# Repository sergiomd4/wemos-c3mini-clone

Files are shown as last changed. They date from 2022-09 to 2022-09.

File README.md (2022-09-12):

C3 Mini Clone
========================================

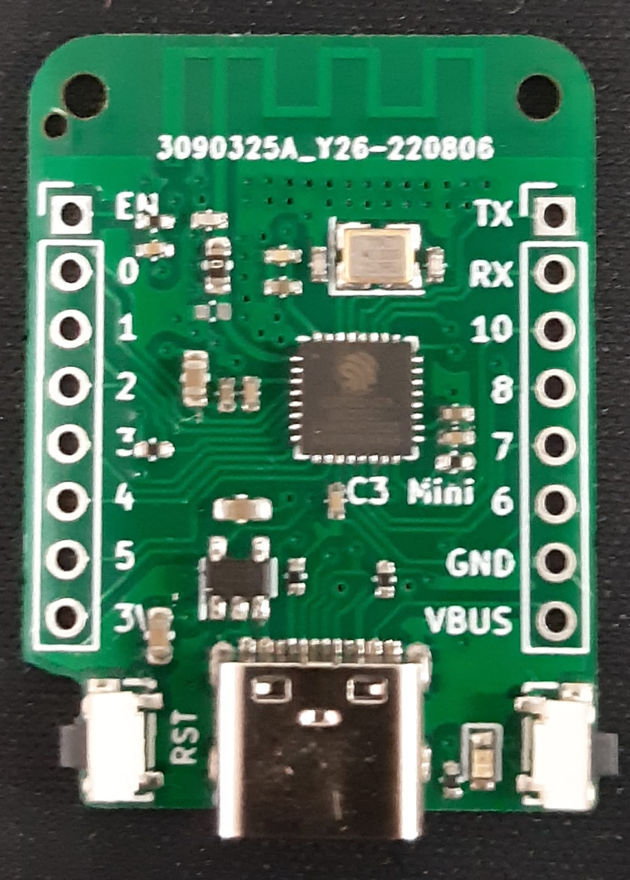
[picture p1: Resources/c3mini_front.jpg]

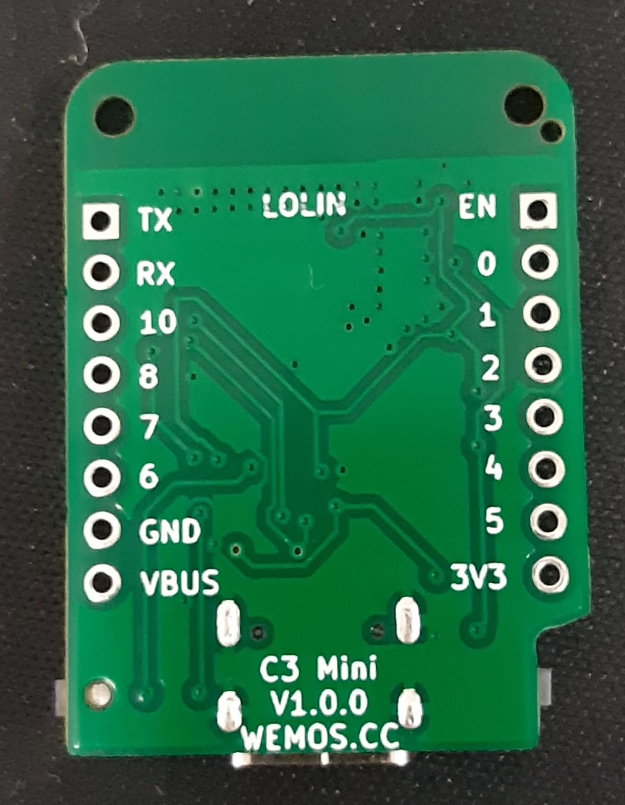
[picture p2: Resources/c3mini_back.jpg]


C3 Mini Clone is a mini WiFi and Bluetooth5 (LE) board based on ESP32-C3FH4

Features
-------------------

* Based on ESP32-C3 WiFi & Bluetooth LE RISC-V Single-Core CPU
* Type-C USB
* 4MB Flash
* 12x IO
* ADC, I2C, SPI, UART
* Compatible with LOLIN D1 mini shields
* Compatible with MicroPython, Arduino, CircuitPython and ESP-IDF
* Default firmware: MicroPython

Technical specifications
-------------------

* Operating Voltage           3.3 V
* Digital I/O Pins            12
* Clock Speed                 160 MHz
* Flash                       4MB
* Size                        34.3*25.4 mm
* Weight                      2.4 g

Repository Contents
-------------------

* **/Production** - Gerber files, drill files, BOM, CPL file
* **/Hardware** - KiCad PCB files
* **/Documents** - Schematics pdf, datasheet

The switch footprint is in the library inside the Hardware folder.

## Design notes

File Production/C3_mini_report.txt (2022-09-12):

Informe de estadísticas de la placa
=============================
- Fecha: 12/09/2022 17:24:44
- Proyecto: C3_mini
- Nombre de placa: C3_mini

Placa
-----
- Ancho: 25,4092 mm
- Alto: 34,1771 mm
- Área: 848,2955 mm cuadrados

Pads
----
- Agujero pasante: 21
- SMD: 125
- Conector: 1
- NPTH: 2

Vías
----
- Vías pasantes: 74
- Ciega/Enterrada: 0
- Microvías: 0

Componentes
----------

| | Lado frontal | Lado trasero | Total |
|---|---|---|---|
|THT: | 2  | 0  | 2  |
|SMD: | 29  | 0  | 29  |
|Total:  | 31  | 0  | 31  |
| | | | |

Agujeros de taladros
-----------

| Cantidad | Forma |  Tamaño X |  Tamaño Y | Revestido | Vía/Pad | Capa inicial | Capa final |
|---|---|---|---|---|---|---|---|
| 74 | Redondo | 0,4000 mm | 0,4000 mm | PTH | Vía | F.Cu | B.Cu |
| 16 | Redondo | 1,0000 mm | 1,0000 mm | PTH | Pad | F.Cu | B.Cu |
| 2 | Redondo | 0,6000 mm | 0,6000 mm | NPTH | Pad | F.Cu | B.Cu |
| 2 |  Ranura | 1,7000 mm | 0,6000 mm | PTH | Pad | F.Cu | B.Cu |
| 2 |  Ranura | 1,4000 mm | 0,6000 mm | PTH | Pad | F.Cu | B.Cu |
| 1 | Redondo | 0,3000 mm | 0,3000 mm | PTH | Pad | F.Cu | B.Cu |

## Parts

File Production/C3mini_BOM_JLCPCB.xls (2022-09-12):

Comment | Designator | Footprint | JLCPCB Part #
SW_2x4x3.5 | SW2,SW1,SW2 | EOS:ST-1114A | C585239
IA0503S | PS1 | Package_TO_SOT_SMD:SOT-23-5 | C82942
1uF | C11,C4,C5,C4,C11 | Capacitor_SMD:C_0402_1005Metric | C52923
15pF | C12,C13,C12 | Capacitor_SMD:C_0402_1005Metric | C1548
100nF | C8,C14,C7,C6,C7,C14,C8 | Capacitor_SMD:C_0402_1005Metric | C1525
5.1k | R2,R1,R2 | Resistor_SMD:R_0402_1005Metric | C25905
10k | R6,R3,R4,R3,R6 | Resistor_SMD:R_0402_1005Metric | C25744
2k | R5 | Resistor_SMD:R_0402_1005Metric | C4109
USB_C_16P | J1 | Connector_USB:USB_C_Receptacle_Palconn_UTC16-G | C2760486
40MHz | Y1 | Crystal:Crystal_SMD_TXC_7M-4Pin_3.2x2.5mm | C9010
10nF | C1 | Capacitor_SMD:C_0402_1005Metric | C15195
ESP32-C3 | U1 | Package_DFN_QFN:QFN-32-1EP_5x5mm_P0.5mm_EP3.45x3.45mm | C2858491
1pF | C15 | Capacitor_SMD:C_0402_1005Metric | C1550
0R | L1 | Inductor_SMD:L_0603_1608Metric | C21189
LED_0603_B | LED1 | LED_SMD:LED_0603_1608Metric | C74343
10uF | C3,C17,C18,C17,C3 | Capacitor_SMD:C_0603_1608Metric | C19702

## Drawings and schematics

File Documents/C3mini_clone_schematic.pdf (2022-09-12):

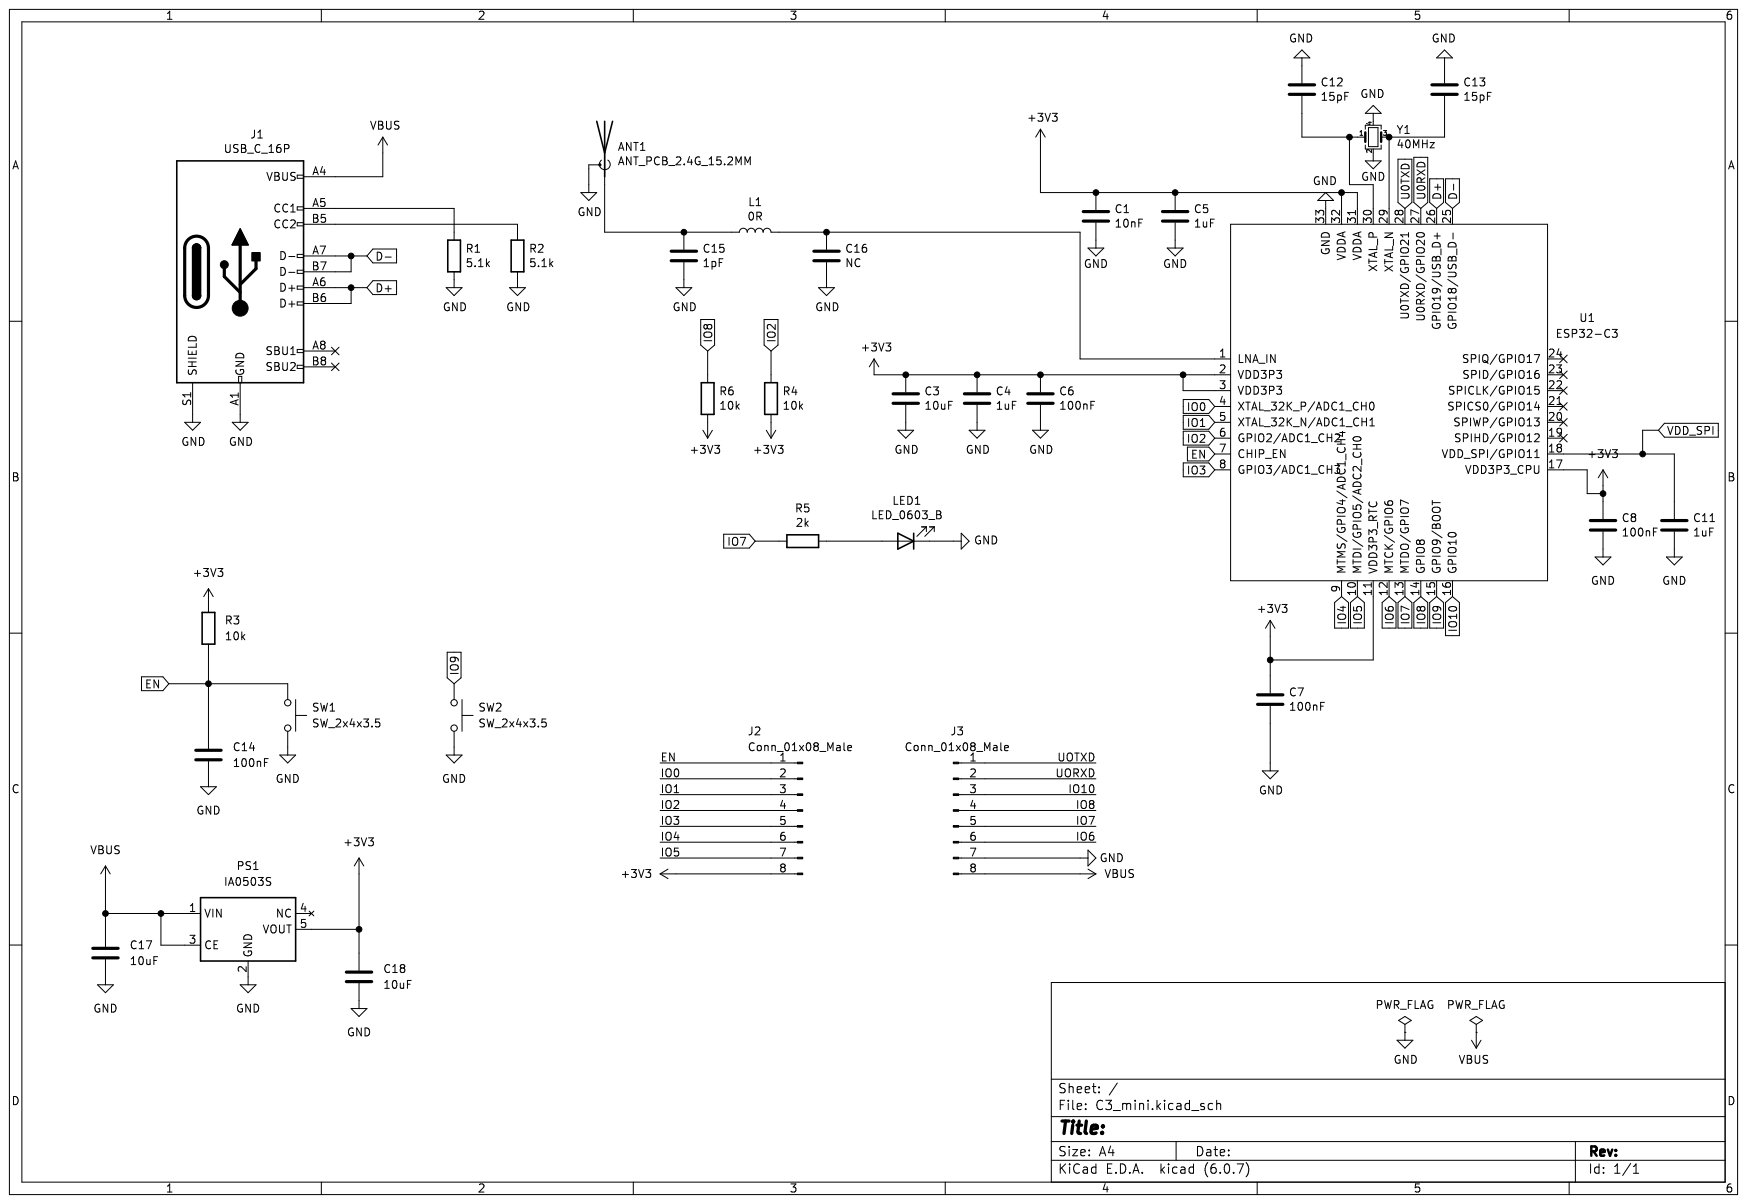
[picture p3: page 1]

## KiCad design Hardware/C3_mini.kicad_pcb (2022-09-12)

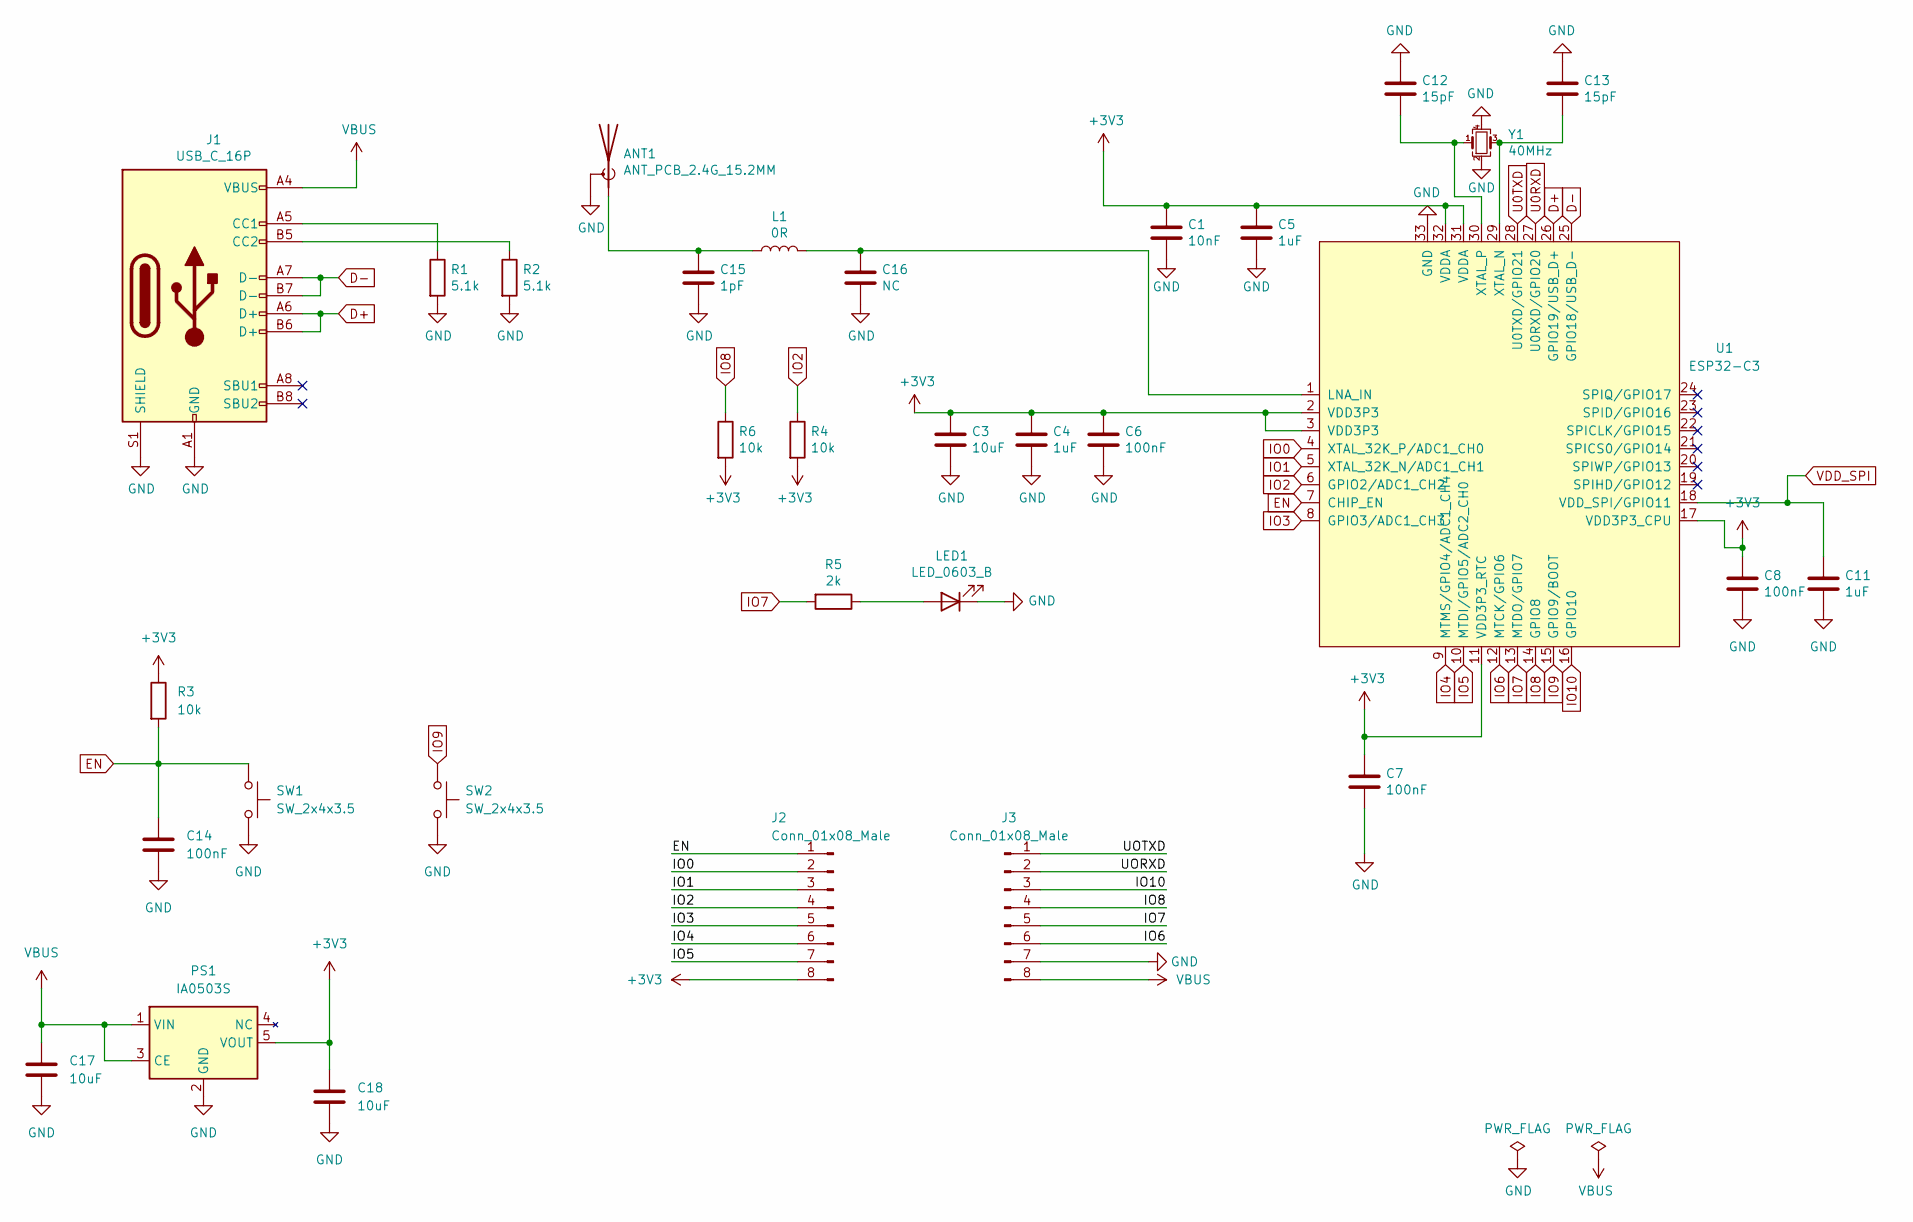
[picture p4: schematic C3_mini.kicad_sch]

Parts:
ANT1: ANT_PCB_2.4G_15.2MM; Texas_SWRA117D_2.4GHz_Right
C1: 10nF; C_0402_1005Metric
C3, C17, C18: 10uF; C_0603_1608Metric
C4, C5, C11: 1uF; C_0402_1005Metric
C6, C7, C8, C14: 100nF; C_0402_1005Metric
C12, C13: 15pF; C_0402_1005Metric
C15: 1pF; C_0402_1005Metric
C16: NC; C_0402_1005Metric
J1: USB_C_16P; USB_C_Receptacle_Palconn_UTC16-G
J2, J3: Conn_01x08_Male
L1: 0R; L_0603_1608Metric
LED1: LED_0603_B; LED_0603_1608Metric
PS1: IA0503S; SOT-23-5
R1, R2: 5.1k; R_0402_1005Metric
R3, R4, R6: 10k; R_0402_1005Metric
R5: 2k; R_0402_1005Metric
SW1, SW2: SW_2x4x3.5; ST-1114A
U1: ESP32-C3; QFN-32-1EP_5x5mm_P0.5mm_EP3.45x3.45mm
Y1: 40MHz; Crystal_SMD_TXC_7M-4Pin_3.2x2.5mm

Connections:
+3V3: C1.1, C3.1, C4.1, C5.1, C6.1, C7.1, C8.1, C18.1, J2.8, PS1.5 (VOUT), R3.1, R4.2, R6.2, U1.2 (VDD3P3), U1.3 (VDD3P3), U1.11 (VDD3P3_RTC), U1.17 (VDD3P3_CPU), U1.31 (VDDA), U1.32 (VDDA)
D+: J1.A6 (D+), J1.B6 (D+), U1.26 (GPIO19/USB_D+)
D-: J1.A7 (D-), J1.B7 (D-), U1.25 (GPIO18/USB_D-)
EN: C14.1, J2.1, R3.2, SW1.1, U1.7 (CHIP_EN)
GND: ANT1.2 (Shield), C1.2, C3.2, C4.2, C5.2, C6.2, C7.2, C8.2, C11.2, C12.1, C13.1, C14.2, C15.2, C16.2, C17.2, C18.2, J1.A1 (GND), J1.A12 (GND), J1.B1 (GND), J1.B12 (GND), J1.S1 (SHIELD), J3.7, LED1.1 (K), PS1.2 (GND), R1.2, R2.2, SW1.2, SW2.2, U1.33 (GND), Y1.2, Y1.4
IO0: J2.2, U1.4 (XTAL_32K_P/ADC1_CH0)
IO1: J2.3, U1.5 (XTAL_32K_N/ADC1_CH1)
IO2: J2.4, R4.1, U1.6 (GPIO2/ADC1_CH2)
IO3: J2.5, U1.8 (GPIO3/ADC1_CH3)
IO4: J2.6, U1.9 (MTMS/GPIO4/ADC1_CH4)
IO5: J2.7, U1.10 (MTDI/GPIO5/ADC2_CH0)
IO6: J3.6, U1.12 (MTCK/GPIO6)
IO7: J3.5, R5.2, U1.13 (MTDO/GPIO7)
IO8: J3.4, R6.1, U1.14 (GPIO8)
IO9: SW2.1, U1.15 (GPIO9/BOOT)
IO10: J3.3, U1.16 (GPIO10)
unnamed: ANT1.1 (A), C15.1, L1.1
unnamed: C12.2, U1.30 (XTAL_P), Y1.1
unnamed: C13.2, U1.29 (XTAL_N), Y1.3
unnamed: C16.1, L1.2, U1.1 (LNA_IN)
unnamed: J1.A5 (CC1), R1.1
unnamed: J1.B5 (CC2), R2.1
unnamed: LED1.2 (A), R5.1
VBUS: C17.1, J1.A4 (VBUS), J1.A9 (VBUS), J1.B4 (VBUS), J1.B9 (VBUS), J3.8, PS1.1 (VIN), PS1.3 (CE)
VDD_SPI: C11.1, U1.18 (VDD_SPI/GPIO11)

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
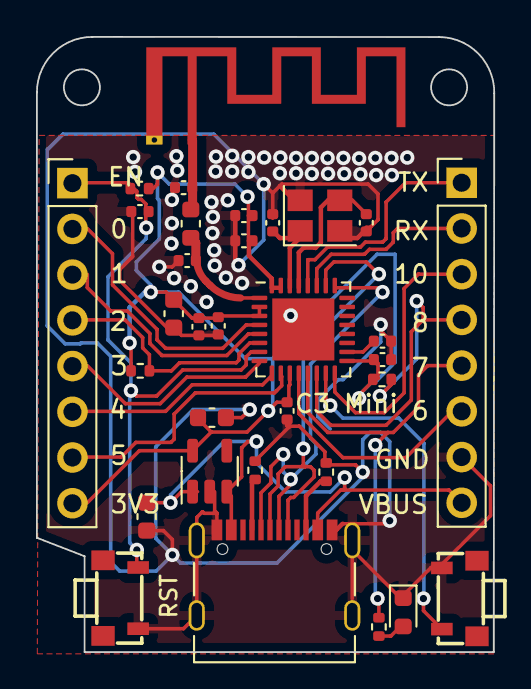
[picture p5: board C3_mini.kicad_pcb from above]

Board: 2 copper layers, 25.4 x 34.2 mm, 32 parts (0 on the bottom side), 27 nets.

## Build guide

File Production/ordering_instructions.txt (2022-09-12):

pcb thickness, 0.8mm
number of layers, 2
soldermask color, Green
silkscreen color, White
finish, HASL
oz copper, 1 oz
stencils, top
min trace width, 0.127mm / 5 mil
min drill size, 0.2000mm / 0.0079 in

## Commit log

2022-09-12 Add Gerber Files
    [C3_mini-B_Cu.gbl, C3_mini-B_Mask.gbs, C3_mini-B_Paste.gbp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]
2022-09-12 Add Drill files
    [C3_mini-NPTH.drl, C3_mini-PTH.drl]
2022-09-12 Add KiCad PCB files
    [C3_mini.kicad_pcb, C3_mini.kicad_sch, C3_mini.sch]
2022-09-12 Add JLCPCB BOM
    [C3mini_BOM_JLCPCB.xls]
